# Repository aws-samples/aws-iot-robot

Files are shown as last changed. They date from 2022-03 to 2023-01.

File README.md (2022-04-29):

# AWS IoT Robot

The code and kit list in this repository enables the building of an AWS IoT and AWS Greengrass (v2) controlled Raspberry Pi robot.  This repository provides the code and assets for an AWS IoT workshop - please refer to that workshop (URL TBC) for detailed build instructions.

There are a number of physical components required to build the robot itself, and this has been done using readily available and low cost parts to hopefully give more people the opportunity to build their own IoT Robot.

## Introduction

You will need an AWS account in which to build this solution.  The solution demonstrates a number of different capabilities of AWS IoT and different ways of implementing those capabilities with the aim of bringing them together to help understand the different approaches and determine what is the best one for a given situation.

The core components of the solution are:
- A Web site/application - Using Angular, the web app displays robot movements, a WebRTC video stream from the PiBot camera and allows control of the camera direction
- Robot - A Raspberry Pi running AWS IoT Greengrass for managing the Lambda functions that control the PiBot actions
- Remote Control - A second Raspberry Pi (Pi Zero W) acts as a remote controller for the robot, using MQTT for communication over wireless.  The remote uses an accelerometer - you tilt the remote and the robot moves in that direction.

CloudFormation templates are provided to create the core AWS resources and also the AWS IoT specific resources.

## What will you build

A robot :-)

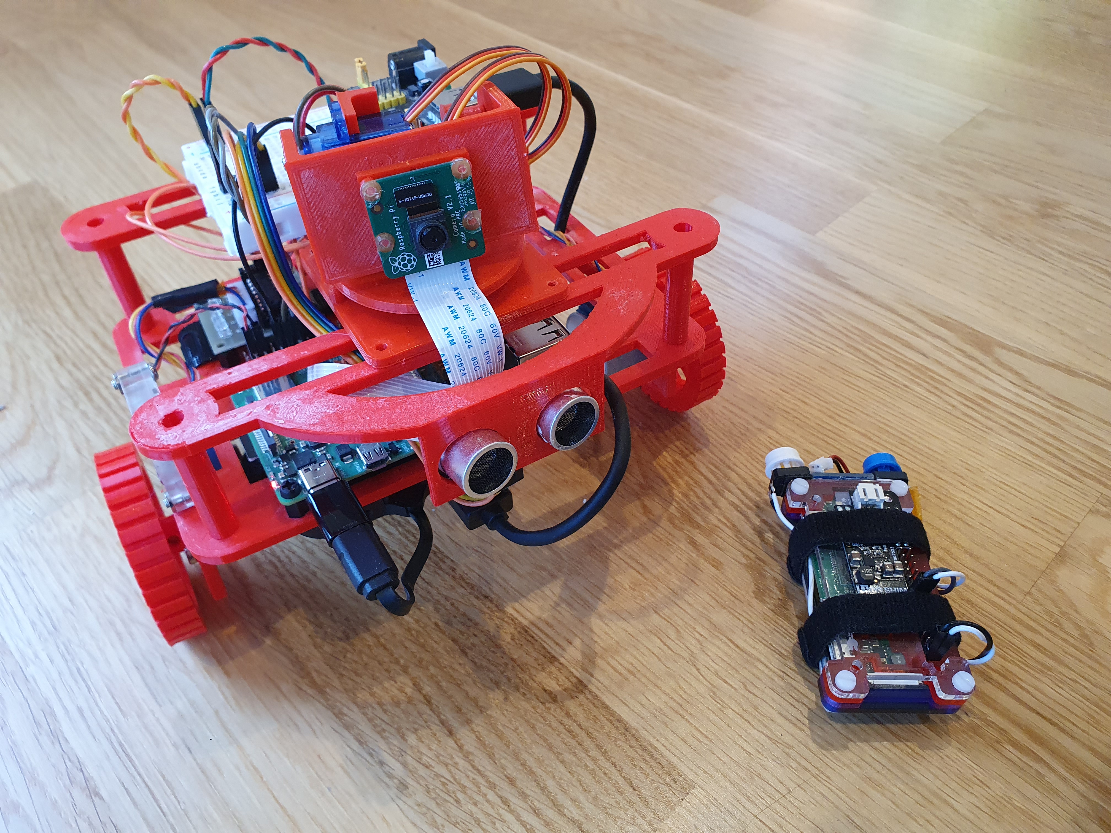
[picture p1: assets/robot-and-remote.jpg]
robot and remote


And a web application that can also control and track the robot and receives a video feed from the camera.

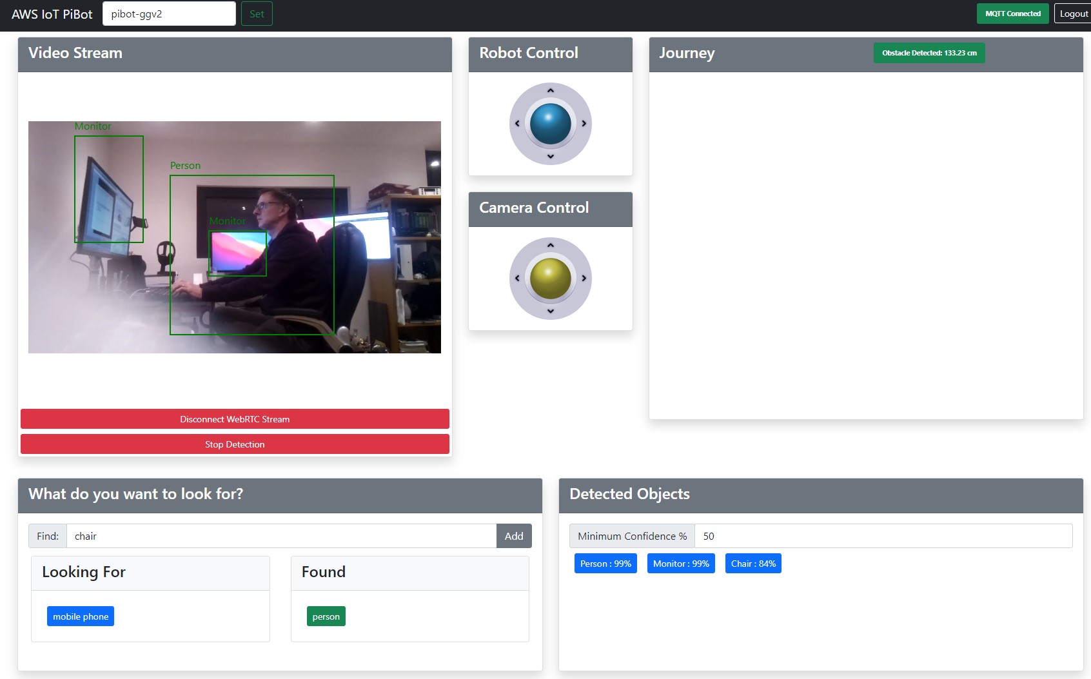
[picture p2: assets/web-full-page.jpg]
robot web application


## Architecture

The architecture diagram below shows the components of the service:

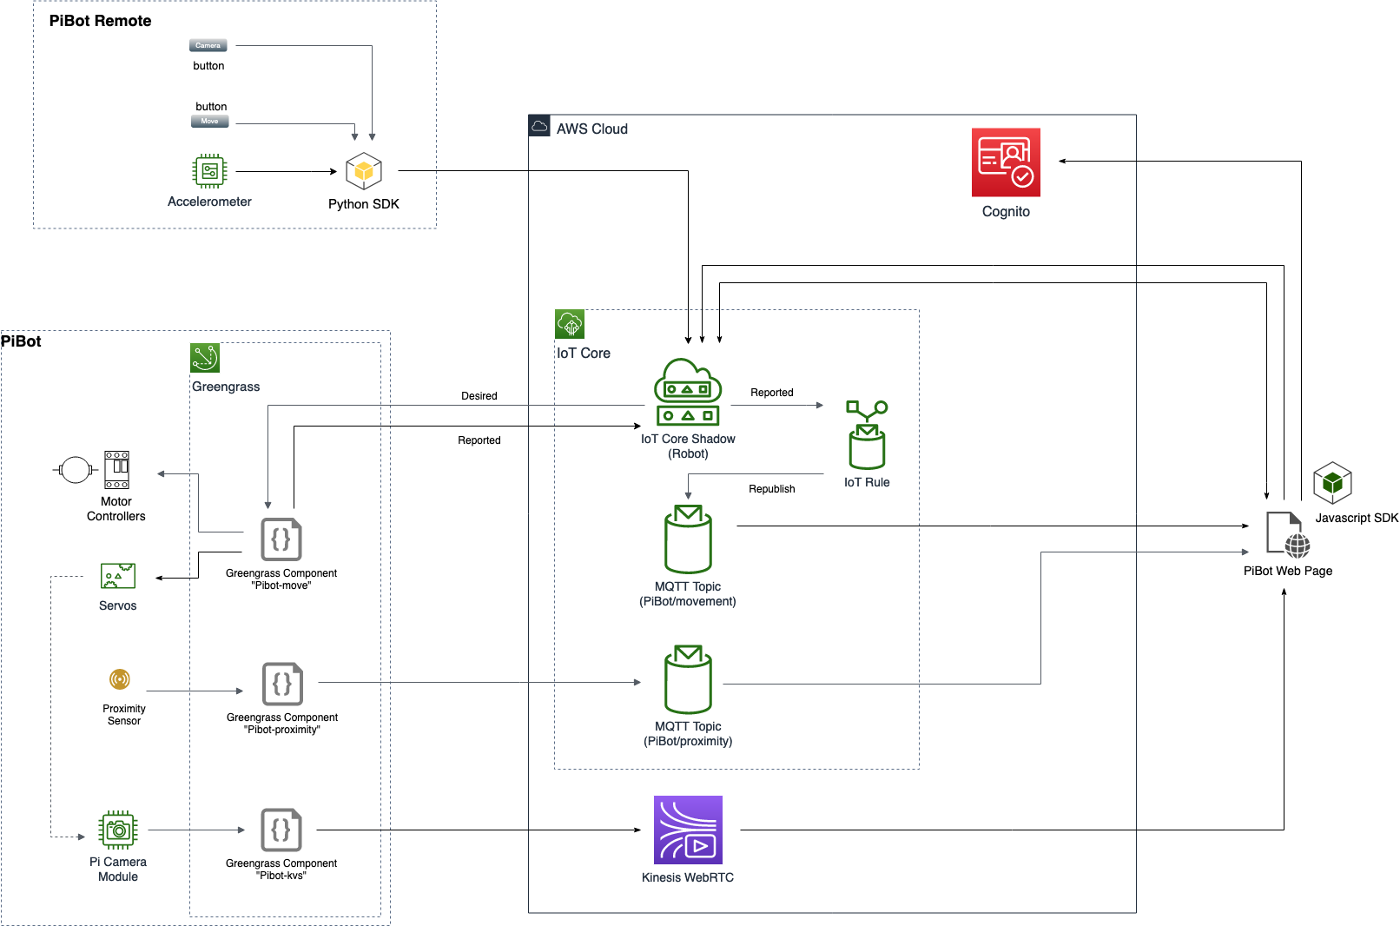
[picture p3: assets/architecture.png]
architecture


## Chassis Build

3D printer files are provided for the chassis of the robot, or you can use your own

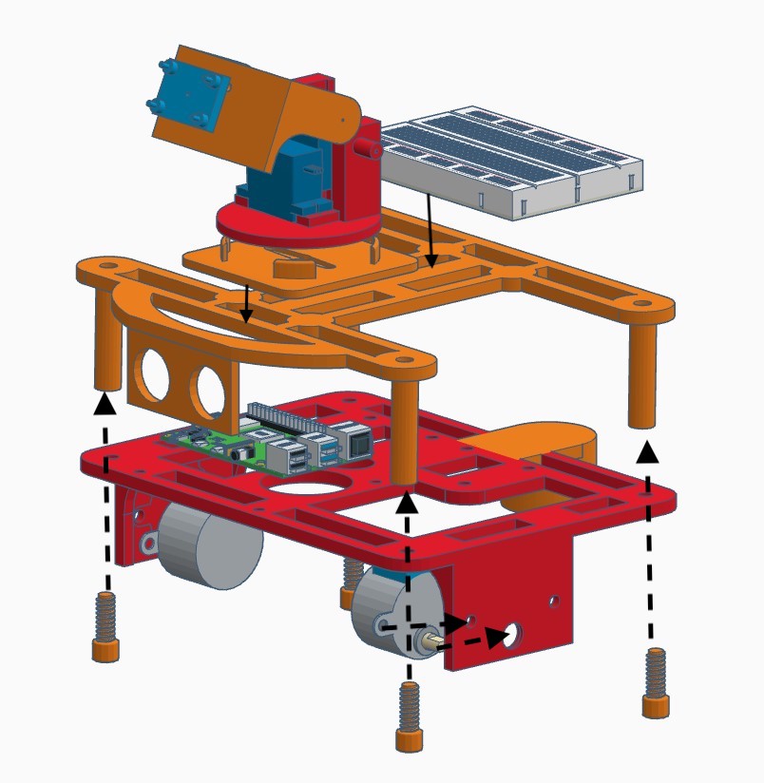
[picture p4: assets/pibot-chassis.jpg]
chassis


## How it works

### Communication Flow
The diagram below shows the communication flow between the PiRemote and PiBot, via IoT Core:

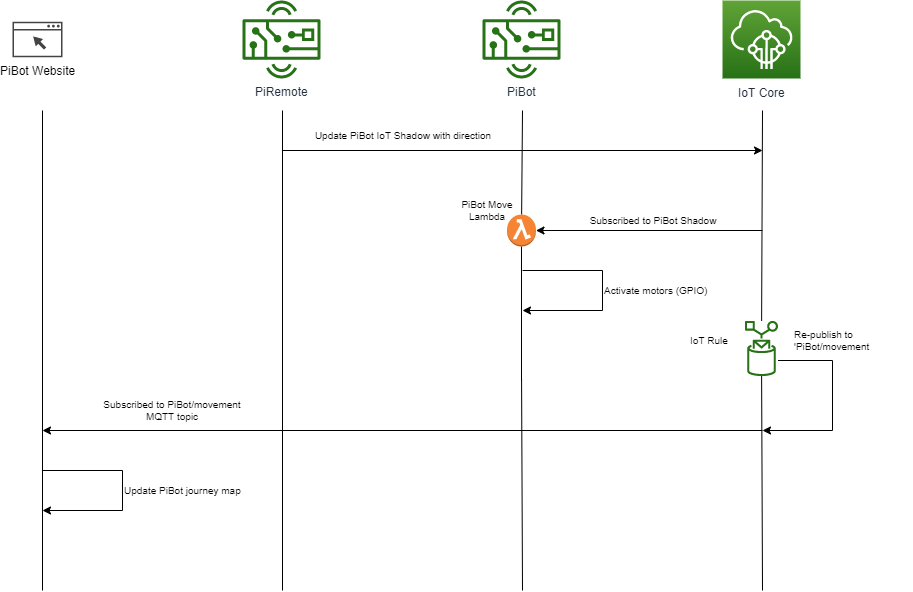
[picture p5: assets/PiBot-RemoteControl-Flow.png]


### Trusted User Provisioning App

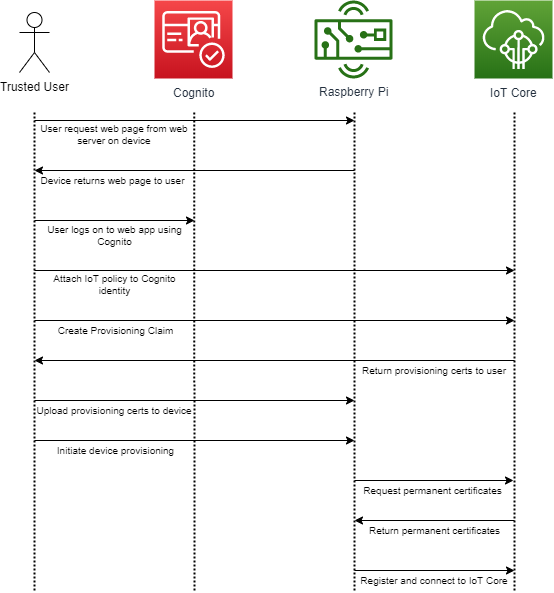
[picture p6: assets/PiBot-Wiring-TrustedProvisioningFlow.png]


## Parts List
The below list is not exhaustive and covers the key components required.  Additional components such as wheels, wiring, breadboard, batteries will be required to complete the build of a full robot
- Raspberry Pi 3 or 4
- Raspberry Pi Zero W (suggest using Lithium-Polymer battery and Li-Po shim)
- 2 x 28BYJ-48 Stepper Motor
- 2 x ULN2003 Motor Driver Board
- 1 x ADXL 345 Accelerometer
- 1 x HC-SR04 ultra-sonic proximity detector
- 2 x push buttons (normally open)
- 5v Battery pack suitable for driving Pi and motors

## Build

The overall build sequence is as follows:

- Setup a Cloud9 IDE
- Build the physical robot, chassis and electronics
- Create Cognito user pools using CloudFormation template
- Implement Greengrass pre-requisites (IAM roles, Fleet Provisioning Template)
- Build the Trusted User Provisioning application
- Provision the robot as an IoT Thing and Greengrass Core Device
- Install Kinesis WebRTC on the robot
- Create and deploy the Greengrass v2 Components
- Build the physical remote control (optional)
- Build the Robot web application
- Create an IoT rule for re-publishing

### Steps

Please refer to the AWS IoT Workshop (https://catalog.us-east-1.prod.workshops.aws/workshops/446304b7-b946-4c40-b78f-08bf0025d8f6) for detailed and step-by-step build instructions.

#### Wiring for PiBot GPIO Pins

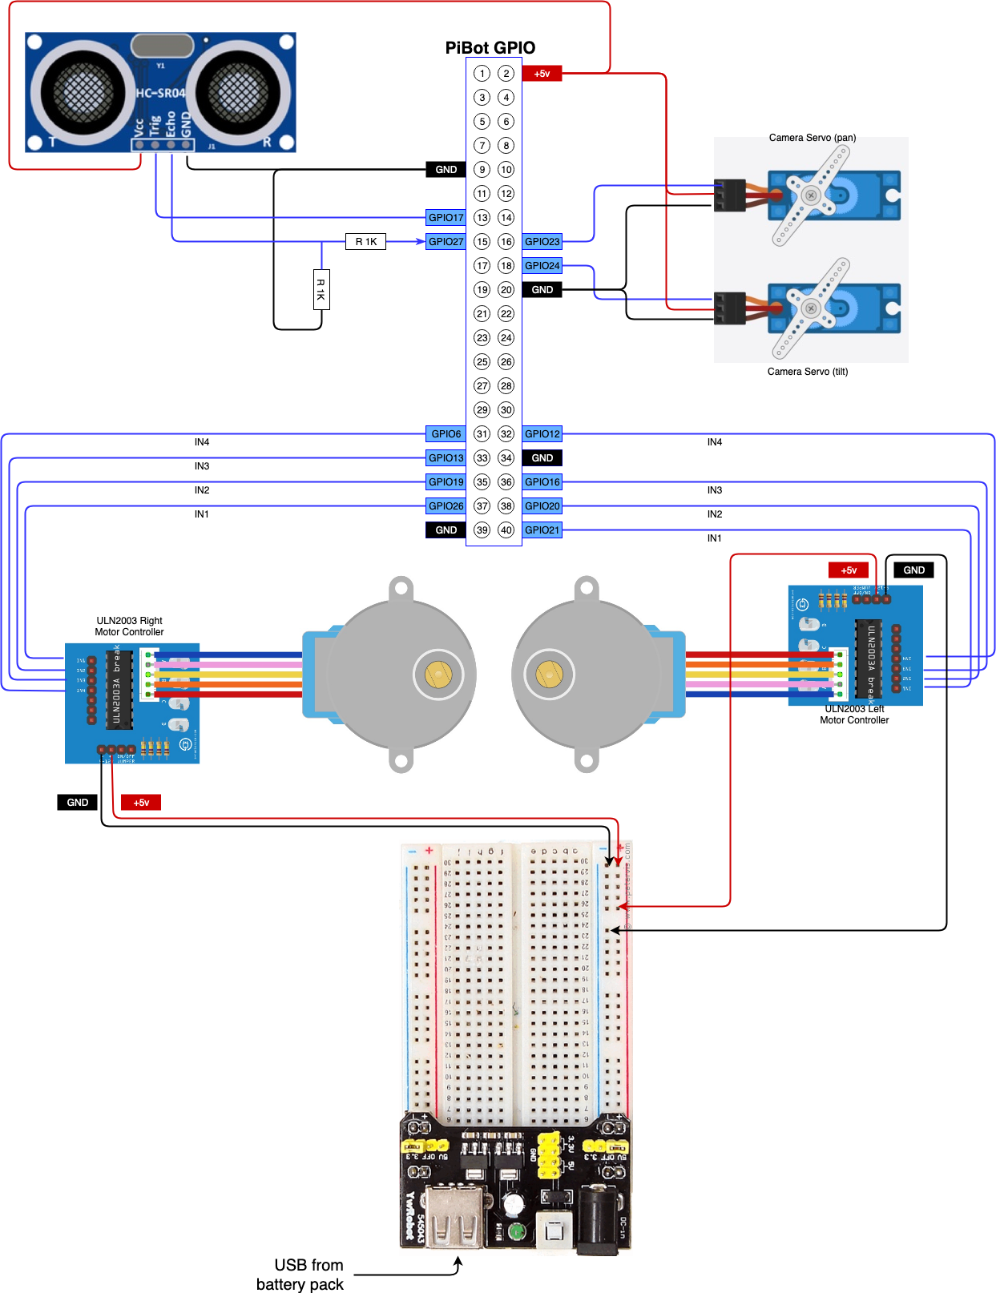
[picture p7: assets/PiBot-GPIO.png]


### Setting up PiRemote

The PiRemote uses the AWS SDK to connect to IoT Core, so does NOT need Greengrass installed.  The scripts on the Pi-Remote are Python 3 based - review the scripts for the Pi-zero-remote for the Python modules that you need to install to run the script.

There is no automated provisioning for the remote yet, so you will need to create the certificates in IoT Core for the Pi-Remote Thing and copy them to the device.  Adapting the PiBot Trusted User Provisioning web app should be pretty simple to provision the Pi-Remote in the same way.

#### Wiring for PiBot Remote GPIO Pins

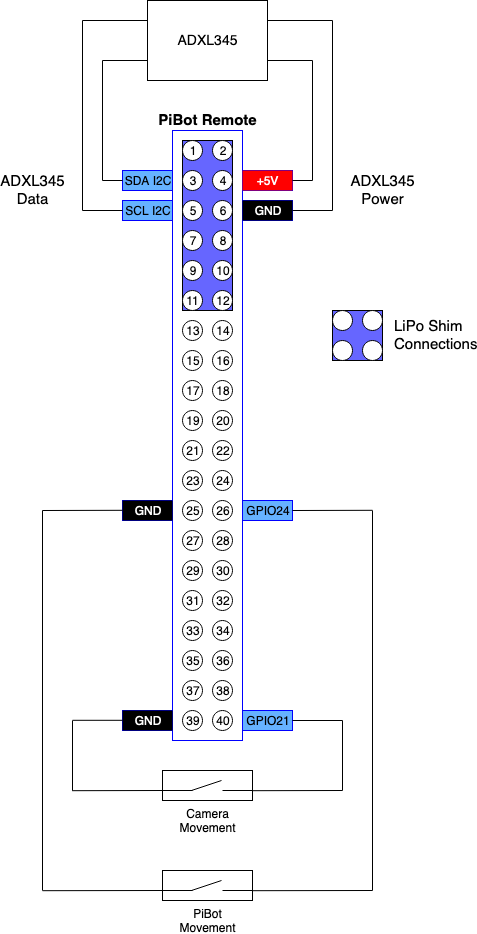
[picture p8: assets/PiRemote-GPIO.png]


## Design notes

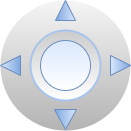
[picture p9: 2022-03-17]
PiBot-website/src/assets/joystick-base.png

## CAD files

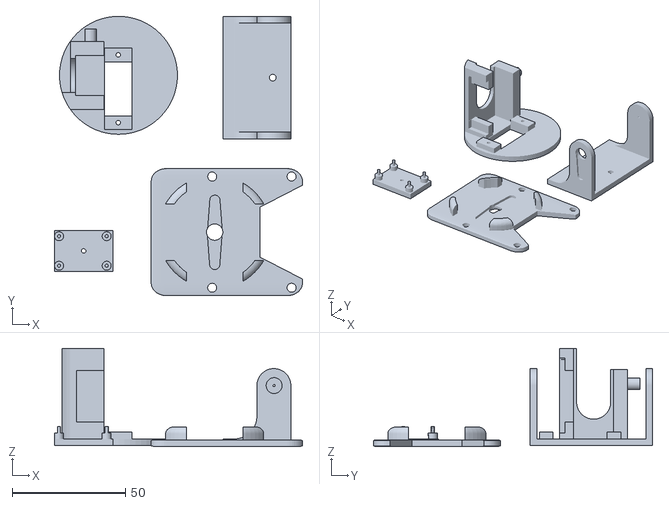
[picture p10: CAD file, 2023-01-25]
3D-Print-Files/camera-mount-single-layer-robot.stl
109.3 x 123.1 x 43.3

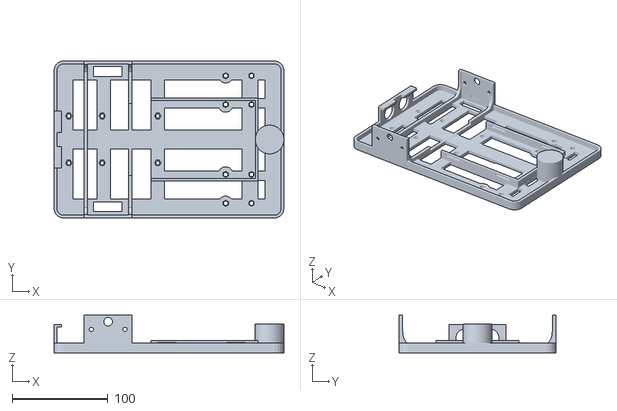
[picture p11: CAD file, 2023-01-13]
3D-Print-Files/Pibot Single Layer.stl
240.0 x 164.0 x 39.3

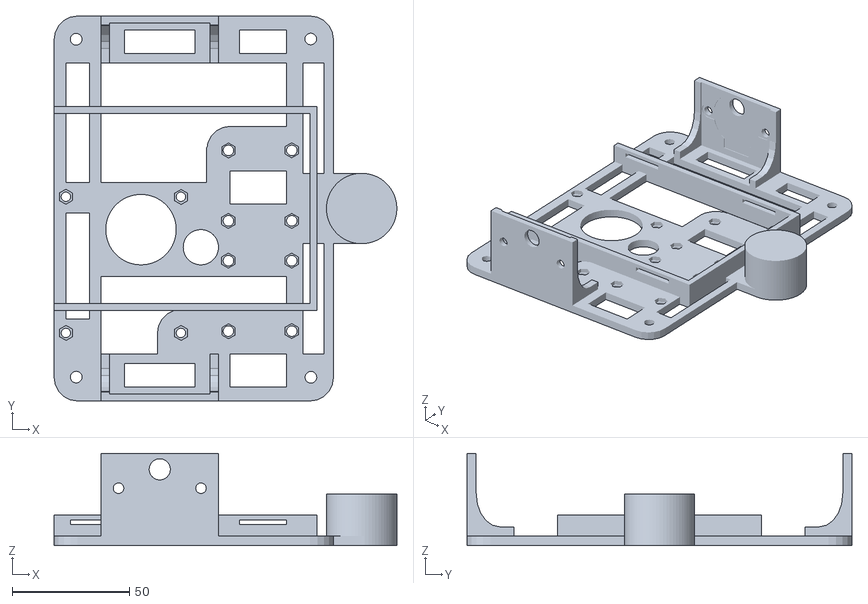
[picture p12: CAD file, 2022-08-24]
3D-Print-Files/Mini Pibot Bottom Layer.stl
146.0 x 164.0 x 39.3

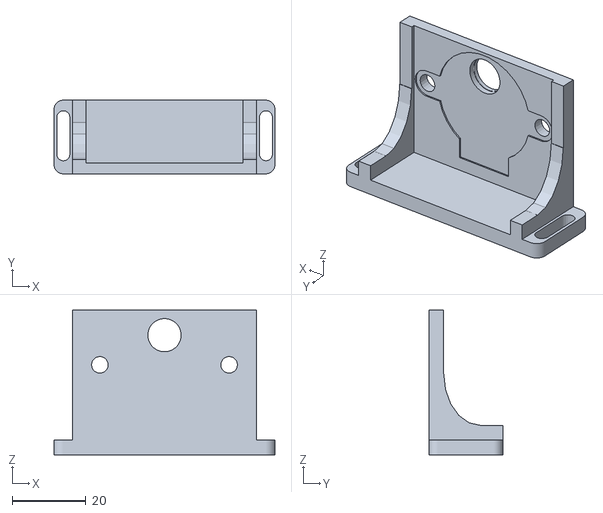
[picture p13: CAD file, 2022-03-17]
3D-Print-Files/Motor Brackets.stl
60.0 x 20.0 x 39.3

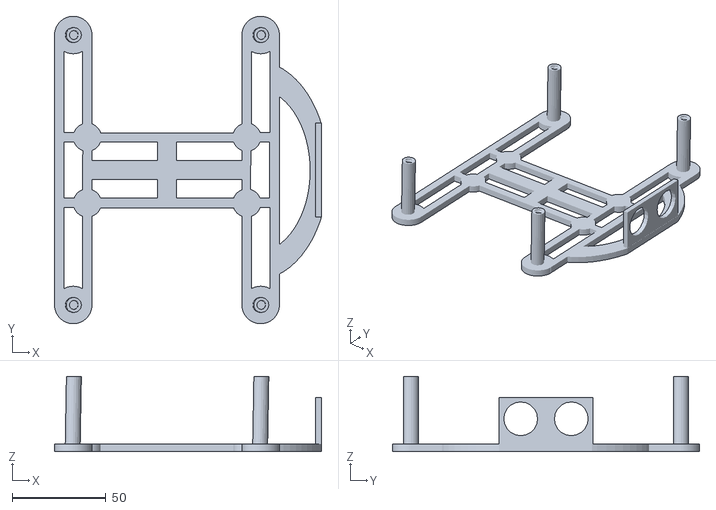
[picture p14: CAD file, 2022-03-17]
3D-Print-Files/Mini PiBot Top Layer.stl
142.4 x 164.0 x 40.1

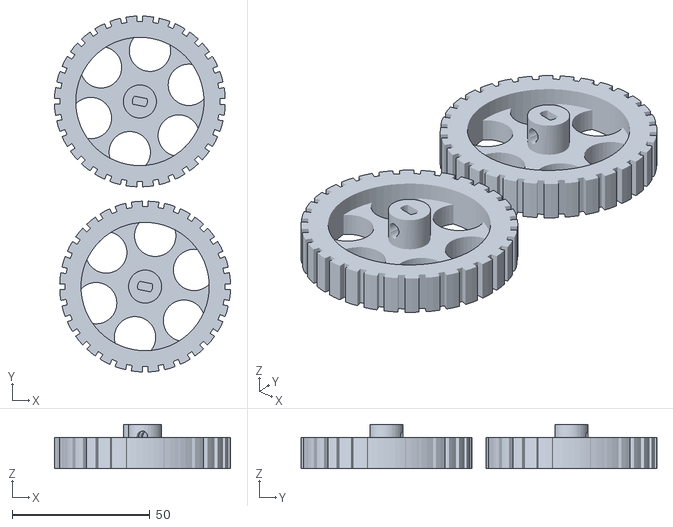
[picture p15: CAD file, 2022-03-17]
3D-Print-Files/Wheels.stl
63.8 x 129.0 x 16.0

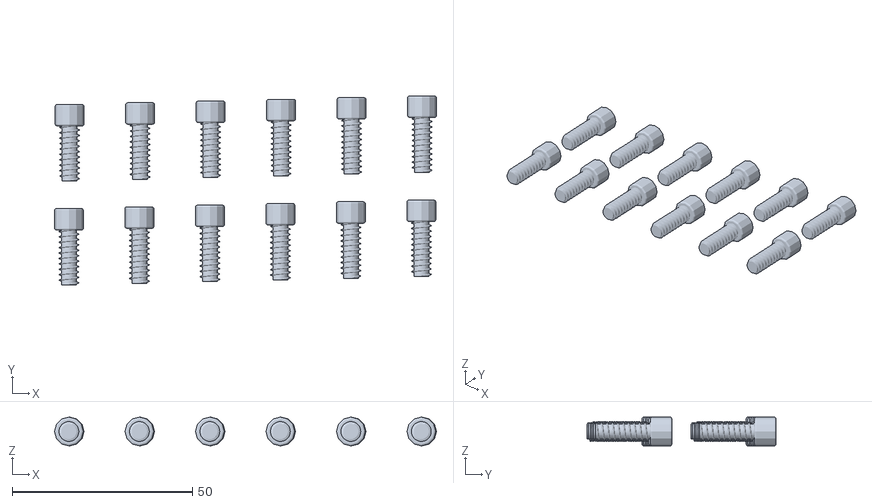
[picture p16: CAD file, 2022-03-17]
3D-Print-Files/Screws.stl
106.0 x 52.5 x 8.00

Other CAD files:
3D-Print-Files/Camera Mount.stl

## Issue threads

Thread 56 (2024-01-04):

Step 6 issues

noorjabermd, 2024-01-04:
Step 6.2.2
npm install error:
I had to reverse the changes in this pull-request (https://github.com/aws-samples/aws-iot-robot/pull/55/commits/0b7717e5619a81331b728307631ff1fa2f6265e2) in order to get npm install to complete. Happened on both 32-bit bullseye and 64-bit Bookworm running on a Raspi 4 4gb.

Step 6.3.3
Not really an issue as it automatically fixes this for you, but "sudo a2enmod cgi" should be "sudo a2enmod cgid".

Thanks,
Noor

gemmerton, 2024-01-10:
I'll re-test 6.2.2

Closed 2024-03-01.

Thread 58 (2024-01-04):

Step 9 issues

noorjabermd, 2024-01-04:
Step 9.3.1
typo
In the tutorial, the "exec_path" line of start-webrtc.py reads: "/homels/pi....". Removed ls -> /home/pi...
This file is imported into Cloud9 in the beginning of the tutorial and does not contain the typo. Consider adjusting the tutorial to only change line 8 with CRED_EP variable instead.

Step 9.4
Component module import error
I was not able to deploy the move and proximity components. In the /greengrass/v2/logs, I keep getting ModuleNotFoundError: No module named 'awsiot' for move and 'boto3' for proximity on line "import awsiot.greengrasscoreipc". I've made sure they (as well as awsiotsdk) are installed as user and that /home/pi/.local/bin was in PATH. I then installed the modules globally and added /home/pi/.local/bin as well as other potentially pertinent paths to PATH for all users and still couldn't deploy successfully. I recreated the component and added a "RequiresPrivilege": true, lifecycle hook, but that didn't deploy either. Input would be appreciated.

The KVS component deployed successfully and I was able to view the stream on AWS Kinesis dashboard on 32-bit Bullseye. In case you run this on 64-bit Bookworm, I had issues with gstreamer and followed the instructions [here](https://forums.raspberrypi.com/viewtopic.php?t=360578) to get streaming to show up.

Thanks,
Noor

gemmerton, 2024-01-05:
Hi Noor,
I've updated (but not yet published) the typo you've identified.

For the Python modules what I have found seems to be required is the following:

`sudo python3 -m pip install awsiotsdk boto3`

I suggest removing the Python libraries previously installed before running the above.

noorjabermd, 2024-01-05:
Thanks @gemmerton, that seemed to work.  I had to add awscli due to a boto3 version conflict.
Uninstall: sudo python3 -m pip uninstall awsiotsdk boto3 awscli
Reinstall: sudo python3 -m pip install awsiotsdk boto3 awscli
Deployed successfully afterwards.

Closed 2024-01-05.

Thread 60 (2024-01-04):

Step 13 Issue

noorjabermd, 2024-01-04:
Step 13.1
Site access error
When navigating to the cloudfront website, I kept getting access denied error. I double-checked the S3 bucket settings and troubleshooted [here](https://repost.aws/knowledge-center/s3-website-cloudfront-error-403) with no obvious reason as to why I was getting the error. Input would be appreciated.

Thanks,
Noor

gemmerton, 2024-01-05:
Hi Noor,
I think I've found the problem, and will update the workshop to cover this.  You'll need to edit the origin in your CloudFront distribution to add the region to the origin domain.  For example:

change:
my-robot-bucket.s3.amazonaws.com

to:
my-robot-bucket.s3.eu-west-1.amazonaws.com

obviously make sure the region you add is the region in which your S3 bucket exists.  Also make sure that when you change the origin domain, re-check that the Origin Access Identity is set correctly - I've seen this reset/clear when you change the domain so re-select if required.  Select "Legacy access identities" and the appropriate Origin access identity from the drop-down.

I will update this to use the more recent origin access control settings in a future release.

noorjabermd, 2024-01-05:
Thanks @gemmerton. That fixed the issue.
I'm now able to login and can select my device from the top left and I see MQTT is connected. Looking at the console, when I click "Connect to the WebRTC Stream" it seems to hang at "Generating ICE Candidates" as VIEWER with no output on the page. I can confirm video from the Pi can be viewed on the AWS KVS dashboard as well as the KVS WebRTC test page. Any ideas?

gemmerton, 2024-01-06:
Hi Noor,

First check is to confirm that the KVS signalling channel has the same name as the IoT Thing/Greengrass Core of the robot.  Have a look at the monitoring tab on the KVS console and you'll be able to see connection attempts by the master and the viewer.  As you're seeing video in the console you will see connections from the master (robot) and just need to see if viewer connections from the web app are also being seen.

I have seen on occassion what you are experiencing and in a lot of cases it has resolved itself by a reboot of the Pi (sorry, I always feel bad suggesting a reboot :-) )

noorjabermd, 2024-01-06:
Thanks @gemmerton.
Ha! No worries. I've rebooted without any change. Not sure why, but the Pibot Site's video stream will not load on Safari even though the WebRTC test page works fine (on Safari). I switched to chrome and I'm now able to see the video stream on the Pibot site. Thanks for all of your help and the tutorial.

gemmerton, 2024-01-10:
Hi Noor, are you okay to close this issue?

noorjabermd, 2024-01-11:
Happy to close. Thanks

Closed 2024-01-11.

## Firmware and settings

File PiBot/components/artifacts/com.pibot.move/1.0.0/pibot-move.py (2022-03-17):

#/*
# * Copyright Amazon.com, Inc. or its affiliates. All Rights Reserved.
# *
# * SPDX-License-Identifier: MIT-0
# * Permission is hereby granted, free of charge, to any person obtaining a copy of this
# * software and associated documentation files (the "Software"), to deal in the Software
# * without restriction, including without limitation the rights to use, copy, modify,
# * merge, publish, distribute, sublicense, and/or sell copies of the Software, and to
# * permit persons to whom the Software is furnished to do so.
# *
# * THE SOFTWARE IS PROVIDED "AS IS", WITHOUT WARRANTY OF ANY KIND, EXPRESS OR IMPLIED,
# * INCLUDING BUT NOT LIMITED TO THE WARRANTIES OF MERCHANTABILITY, FITNESS FOR A
# * PARTICULAR PURPOSE AND NONINFRINGEMENT. IN NO EVENT SHALL THE AUTHORS OR COPYRIGHT
# * HOLDERS BE LIABLE FOR ANY CLAIM, DAMAGES OR OTHER LIABILITY, WHETHER IN AN ACTION
# * OF CONTRACT, TORT OR OTHERWISE, ARISING FROM, OUT OF OR IN CONNECTION WITH THE
# * SOFTWARE OR THE USE OR OTHER DEALINGS IN THE SOFTWARE.
# */

import time
import sys
import threading
import traceback
import json
import RPi.GPIO as gpio

import awsiot.greengrasscoreipc
import awsiot.greengrasscoreipc.client as client
from awsiot.greengrasscoreipc.model import (
    SubscribeToIoTCoreRequest,
    PublishToIoTCoreRequest,
    QOS,
    IoTCoreMessage
)
#from awsiot.greengrasscoreipc.model import GetThingShadowRequest
#from awsiot.greengrasscoreipc.model import UpdateThingShadowRequest

ipc_client = awsiot.greengrasscoreipc.connect()
camera_pin_x = int(sys.argv[1])
camera_pin_y = int(sys.argv[2])
lcoil_pins = list(map(int,sys.argv[3].split(",")))
rcoil_pins = list(map(int,sys.argv[4].split(",")))
TIMEOUT = 10
client_id = sys.argv[5]
thing_name = sys.argv[5]

subscribe_topic = "$aws/things/"+thing_name+"/shadow/update/accepted"
publish_topic = "$aws/things/"+thing_name+"/shadow/update"
sub_qos = QOS.AT_MOST_ONCE
pub_qos = QOS.AT_LEAST_ONCE
shadow_value = { "move_x": "S", "move_y": "S", "cam_x": "S", "cam_y": "S" }
camera_angle_x = 90
camera_angle_y = 90

gpio.setmode(gpio.BCM)
gpio.setwarnings(False)

step_count = 8
seq_f = list(range(0,step_count))
seq_f = [[1,0,0,0],[1,1,0,0],[0,1,0,0],[0,1,1,0],[0,0,1,0],[0,0,1,1],[0,0,0,1],[1,0,0,1]]

seq_r = list(range(0,step_count))
seq_r = [[1,0,0,1],[0,0,0,1],[0,0,1,1],[0,0,1,0],[0,1,1,0],[0,1,0,0],[1,1,0,0],[1,0,0,0]]

for lpin,rpin in zip(lcoil_pins,rcoil_pins):
    gpio.setup(lpin,gpio.OUT)
    gpio.setup(rpin,gpio.OUT)

gpio.setup(camera_pin_x,gpio.OUT)
gpio.setup(camera_pin_y,gpio.OUT)

class MotorThread(threading.Thread):
    def __init__(self,motor_name,pins,delay=0.01,direction="S"):
        threading.Thread.__init__(self)

        self.thread_id = motor_name
        self.direction = direction
        self.delay = delay
        self.pins = pins

        self.terminate_event = threading.Event()
        self.start_event = threading.Event()
        self.reset_event = threading.Event()

    def run(self):
        while not self.terminate_event.is_set():
            while self.start_event.is_set():
                if self.direction == "f":
                    self.do_steps(seq_f)
                elif self.direction == "b":
                    self.do_steps(seq_r)

    def set_direction(self,direction):
        self.direction = direction

    def set_delay(self,delay):
        self.delay = delay

    def start_motor(self):
        self.start_event.set()

    def stop_motor(self):
        self.start_event.clear()

    def set_steps(self,num_steps):
        self.num_steps = num_steps

    def do_steps(self,arr):
        for steps in range(self.num_steps):
            for step in range(step_count):
                pin_idx = 0
                for pin in self.pins:
                    gpio.output(pin,arr[step][pin_idx])
                    pin_idx += 1
                time.sleep(self.delay)

    def restart_motor(self):
        # reset only if motor is running. otherwise start motor afresh
        if self.start_event.is_set():
            self.reset_event.set()
        else:
            self.start_event.set()

    def terminate(self):
        self.terminate_event.set()

class CameraThread(threading.Thread):
    def __init__(self,servo_name,servo_pin,angle=90,dir="f"):
        threading.Thread.__init__(self)

        print("Init servo:",servo_name,servo_pin)
        self.servo = gpio.PWM(servo_pin, 100)
        self.name = servo_name
        self.angle = angle
        self.dir = dir
        self.angle = 90
        self.set_angle(self.angle)

        self.start_event = threading.Event()
        self.terminate_event = threading.Event()

    def run(self):
        print("run")

    def start_servo(self):
        self.servo.start(5)

    def set_angle(self,angle):
        print("Setting angle:",self.name,angle)
        self.angle = angle
        duty = float(angle) / 10.0 + 2.5
        self.servo.ChangeDutyCycle(duty)

    def get_angle(self):
        return int(self.angle)

    def stop_servo(self):
        print("Stopping servo",self.name)
        self.servo.ChangeDutyCycle(0)

    def terminate(self):
        self.terminate_event.set()

class StreamHandler(client.SubscribeToIoTCoreStreamHandler):
    def __init__(self):
        super().__init__()

    def on_stream_event(self, event: IoTCoreMessage) -> None:
        try:
            message_string = str(event.message.payload, "utf-8")
            # Load message and check values
            jsonmsg = json.loads(message_string)

            if jsonmsg['state']['desired']['direction']:
                print("Move motor or camera: ",jsonmsg)
                if "move_x" in jsonmsg['state']['desired']['direction']:
                    set_motor_direction(jsonmsg['state']['desired']['direction'])
                if "cam_x" in jsonmsg['state']['desired']['direction']:
                    set_camera_angle(jsonmsg['state']['desired']['direction'])
                #pub_thread.publish(jsonmsg)
        except:
            traceback.print_exc()

    def on_stream_error(self, error: Exception) -> bool:
        # Handle error.
        return True  # Return True to close stream, False to keep stream open.

    def on_stream_closed(self) -> None:
        # Handle close.
        pass

class update_thing_shadow_request(threading.Thread):
    def __init__(self,name="pub"):
        threading.Thread.__init__(self)
        self.name = name

    def run(self):
        print("run")

    def set_topic(self,topic):
        self.topic = topic

    def publish(self,payload):
        try:
            payload['state']['reported'] = payload['state']['desired']
            pub_req = PublishToIoTCoreRequest()
            pub_req.topic_name = self.topic
            pub_req.payload = json.dumps(payload).encode('utf-8')
            pub_req.qos = pub_qos
            send_msg = ipc_client.new_publish_to_iot_core()
            send_msg.activate(pub_req)
            msg_resp = send_msg.get_response()
            #msg_resp.result(TIMEOUT)
        except Exception as e:
            print("Error update shadow", type(e), e)
            # except ConflictError | UnauthorizedError | ServiceError

def set_motor_direction(direction):
    # set the direction for the motors based on shadow values
    # this function only called if the shadow value has changed
    motor_l_delay = 0.0008
    motor_r_delay = 0.0008

    if direction['move_x'] == "F":
        #print("Forward")
        motorL.set_direction("f")
        motorR.set_direction("b")
        if direction['move_y'] == "L":
            #print(" and to the left")
            motor_l_delay *= 2
        elif direction['move_y'] == "R":
            #print(" and to the right")
            motor_r_delay *= 2 
    elif direction['move_x'] == "B":
        #print("Backwards")
        motorL.set_direction("b")
        motorR.set_direction("f")
        if direction['move_y'] == "L":
            #print(" and to the left")
            motor_r_delay *= 2
        elif direction['move_y'] == "R":
            #print(" and to the right")
            motor_l_delay *= 2
    elif direction['move_x'] == "S":
        # pure left or right, so both motors in same dir at same speed
        if direction['move_y'] == "L":
            #print("Only Left")
            motorL.set_direction("b")
            motorR.set_direction("b")
        elif direction['move_y'] == "R":
            #print("Only Right")
            motorL.set_direction("f")
            motorR.set_direction("f")

    if direction['move_x'] != "S" or direction['move_y'] != "S":
        motorL.set_delay(motor_l_delay)
        motorR.set_delay(motor_r_delay)
        motorL.set_steps(100)
        motorR.set_steps(100)
        motorL.start_motor()
        motorR.start_motor()
    else:
        motorL.stop_motor()
        motorR.stop_motor()

def set_camera_angle(direction):
    #print("Set camera angle:",direction['cam_x'],direction['cam_y'])

    if (servoX.get_angle() != int(direction['cam_x'])):
        servoX.start_servo()
        servoX.set_angle(int(direction['cam_x']))
        time.sleep(0.5)
        servoX.stop_servo()

    if (servoY.get_angle() != int(direction['cam_y'])):
        servoY.start_servo()
        servoY.set_angle(int(direction['cam_y']))
        time.sleep(0.5)
        servoY.stop_servo()

print("Launching thread to manage motors...")
motorL = MotorThread("LeftMotor",lcoil_pins)
motorL.start()
motorR = MotorThread("RightMotor",rcoil_pins)
motorR.start()
print("motor init complete")

print("Launching Camera servo threads")
servoX = CameraThread("axis_x",camera_pin_x)
servoY = CameraThread("axis_y",camera_pin_y)

#subscribe to shadow update topic
print("Subscribing to MQTT topic for shadow")
request = SubscribeToIoTCoreRequest()
request.topic_name = subscribe_topic 
request.qos = sub_qos
handler = StreamHandler()
operation = ipc_client.new_subscribe_to_iot_core(handler) 
future = operation.activate(request)
future.result(TIMEOUT)
print("Finished subscription")

pub_thread = update_thing_shadow_request("pub_shadow")
pub_thread.set_topic(publish_topic)

# Keep main thread running
while True:
    time.sleep(10)

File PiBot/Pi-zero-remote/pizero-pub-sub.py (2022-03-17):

# Copyright Amazon.com, Inc. or its affiliates. All Rights Reserved.
# SPDX-License-Identifier: Apache-2.0.
# Modifications Copyright 2022 Amazon.com, Inc. or its affiliates. Licensed under the MIT-0 License.

import argparse
from awscrt import io, mqtt, auth, http
from awsiot import mqtt_connection_builder
import sys
import threading
import time
from uuid import uuid4
import json
import time

## AWS IoT Robot modifications
import board
import busio
import adafruit_adxl34x
import RPi.GPIO as GPIO

# for the accelerometer module
i2c = busio.I2C(board.SCL, board.SDA)
accelerometer = adafruit_adxl34x.ADXL345(i2c)

# for the push button
move_button_gpio = 7
camera_button_gpio = 21
GPIO.setwarnings(False)
GPIO.setmode(GPIO.BCM)
GPIO.setup(move_button_gpio, GPIO.IN, pull_up_down=GPIO.PUD_UP) # Move button - initialises with down/off
GPIO.setup(camera_button_gpio, GPIO.IN, pull_up_down=GPIO.PUD_UP) # Camera button

# For capturing current vals so only publish message on change
current_vals = {}
received_count = 0
received_all_event = threading.Event()
payload = { "move_x": "S", "move_y": "S", "cam_x": "S", "cam_y": "S" }
## END AWS IoT Robot modifications

parser = argparse.ArgumentParser(description="Send and receive messages through and MQTT connection.")
parser.add_argument('--endpoint', required=True, help="Your AWS IoT custom endpoint, not including a port. " +
                                                      "Ex: \"abcd123456wxyz-ats.iot.us-east-1.amazonaws.com\"")
parser.add_argument('--port', type=int, help="Specify port. AWS IoT supports 443 and 8883.")
parser.add_argument('--cert', help="File path to your client certificate, in PEM format.")
parser.add_argument('--key', help="File path to your private key, in PEM format.")
parser.add_argument('--root-ca', help="File path to root certificate authority, in PEM format. " +
                                      "Necessary if MQTT server uses a certificate that's not already in " +
                                      "your trust store.")
parser.add_argument('--client-id', default="pi-remote", help="Client ID for MQTT connection.")
parser.add_argument('--topic', default="$aws/things/pb_pibot/shadow/update", help="Topic to subscribe to, and publish messages to.")
parser.add_argument('--verbosity', choices=[x.name for x in io.LogLevel], default=io.LogLevel.NoLogs.name,
    help='Logging level')

# Using globals to simplify sample code
args = parser.parse_args()

io.init_logging(getattr(io.LogLevel, args.verbosity), 'stderr')

# Callback when connection is accidentally lost.
def on_connection_interrupted(connection, error, **kwargs):
    print("Connection interrupted. error: {}".format(error))

# Callback when an interrupted connection is re-established.
def on_connection_resumed(connection, return_code, session_present, **kwargs):
    print("Connection resumed. return_code: {} session_present: {}".format(return_code, session_present))

    if return_code == mqtt.ConnectReturnCode.ACCEPTED and not session_present:
        print("Session did not persist. Resubscribing to existing topics...")
        resubscribe_future, _ = connection.resubscribe_existing_topics()

        # Cannot synchronously wait for resubscribe result because we're on the connection's event-loop thread,
        # evaluate result with a callback instead.
        resubscribe_future.add_done_callback(on_resubscribe_complete)

def on_resubscribe_complete(resubscribe_future):
        resubscribe_results = resubscribe_future.result()
        print("Resubscribe results: {}".format(resubscribe_results))

        for topic, qos in resubscribe_results['topics']:
            if qos is None:
                sys.exit("Server rejected resubscribe to topic: {}".format(topic))

# Callback when the subscribed topic receives a message
def on_message_received(topic, payload, dup, qos, retain, **kwargs):
    print("Received message from topic '{}': {}".format(topic, payload))

## AWS IoT Robot modifications
# Get accelerometer and button values
def get_accelerometer():
    while True:
        #print("%f %f %f"%accelerometer.acceleration)
        time.sleep(0.25)
        acc = accelerometer.acceleration
        changed = False

        # X Axis - set forward or backward
        if int(acc[0]) >= 2:
            x = "F"
        elif int(acc[0]) <= -2:
            x = "B"
        else:
            x = "S"

        # Y Axis - set left or right
        if int(acc[1]) >= 2:
            y = "L"
        elif int(acc[1]) <= -2:
            y = "R"
        else:
            y = "S"

        # if button not pressed then stop if not already done sone
        if GPIO.input(move_button_gpio) == GPIO.HIGH:
            if payload["move_x"] != "S" or payload["move_y"] != "S":
                # stop movement as button not pressed
                changed = True
                payload["move_x"] = "S"
                payload["move_y"] = "S"
        else:
            if x != payload["move_x"] or y != payload["move_y"]:
                # Move button pressed so update movement
                changed = True
                payload["move_x"] = x
                payload["move_y"] = y


        if GPIO.input(camera_button_gpio) == GPIO.HIGH:
            if payload["cam_x"] != "S" or payload["cam_y"] != "S":
                # stop movement as button not pressed
                changed = True
                payload["cam_x"] = "S"
                payload["cam_y"] = "S"
        else:
            if x != payload["cam_x"] or y != payload["cam_y"]:
                # Move button pressed so update movement
                changed = True
                payload["cam_x"] = x
                payload["cam_y"] = y

        # Publish to PiBot shadow topic, but only if changed
        if changed:
            publish_message(payload)

def publish_message(message):
    full_msg = { "state": { "desired": { "direction": message } } }
    message_json = json.dumps(full_msg)
    #print("Publishing: ",full_msg)
    mqtt_connection.publish(
        topic=args.topic,
        payload=message_json,
        qos=mqtt.QoS.AT_LEAST_ONCE)
## END AWS IoT Robot modifications
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

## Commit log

2022-03-17 Bump aws-iot-device-sdk-v2 from 1.5.2 to 1.6.0 in /PiBot-website
    Bumps [aws-iot-device-sdk-v2](https://github.com/aws/aws-iot-device-sdk-js-v2) from 1.5.2 to 1.6.0.
    - [Release notes](https://github.com/aws/aws-iot-device-sdk-js-v2/releases)
    - [Commits](https://github.com/aws/aws-iot-device-sdk-js-v2/compare/v1.5.2...v1.6.0)
    ---
    updated-dependencies:
    - dependency-name: aws-iot-device-sdk-v2
    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
2022-08-24 updated 3d print files
    [Camera Mount.stl, Mini Pibot Bottom Layer.stl]
2022-11-22 Bump engine.io and socket.io in /PiBot-provisioning-app
    Bumps [engine.io](https://github.com/socketio/engine.io) and [socket.io](https://github.com/socketio/socket.io). These dependencies needed to be updated together.
    Updates `engine.io` from 6.1.3 to 6.2.1
    - [Release notes](https://github.com/socketio/engine.io/releases)
    - [Changelog](https://github.com/socketio/engine.io/blob/main/CHANGELOG.md)
    - [Commits](https://github.com/socketio/engine.io/compare/6.1.3...6.2.1)
    Updates `socket.io` from 4.4.1 to 4.5.3
    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
2022-11-22 Bump engine.io and socket.io in /PiBot-website
    - [Release notes](https://github.com/socketio/socket.io/releases)
    - [Changelog](https://github.com/socketio/socket.io/blob/main/CHANGELOG.md)
    - [Commits](https://github.com/socketio/socket.io/c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
2023-01-25 3d print file additions
    [camera-mount-single-layer-robot.stl]
2023-05-24 Bump socket.io-parser from 4.2.2 to 4.2.3 in /PiBot-provisioning-app
    Bumps [socket.io-parser](https://github.com/socketio/socket.io-parser) from 4.2.2 to 4.2.3.
    - [Release notes](https://github.com/socketio/socket.io-parser/releases)
    - [Changelog](https://github.com/socketio/socket.io-parser/blob/main/CHANGELOG.md)
    - [Commits](https://github.com/socketio/socket.io-parser/compare/4.2.2...4.2.3)
    - dependency-name: socket.io-parser
    dependency-type: indirect
    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
2023-05-24 Bump socket.io-parser from 4.2.2 to 4.2.3 in /PiBot-website
    ...
    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
2024-06-20 Bump ws, engine.io and socket.io-adapter in /PiBot-website
    Bumps [ws](https://github.com/websockets/ws), [engine.io](https://github.com/socketio/engine.io) and [socket.io-adapter](https://github.com/socketio/socket.io-adapter). These dependencies needed to b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
    Updates `ws` from 8.11.0 to 8.17.1
    - [Release notes](https://github.com/websockets/ws/releases)
    - [Commits](https://github.com/websockets/ws/compare/8.11.0...8.17.1)
    Updates `engine.io` from 6.5.4 to 6.5.5
    - [Commits](https://github.com/socketio/engine.io/compare/6.5.4...6.5.5)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
2024-06-20 Bump ws and socket.io in /PiBot-provisioning-app
    Bumps [ws](https://github.com/websockets/ws) and [socket.io](https://github.com/socketio/socket.io). These dependencies needed to be updated together.
    Updates `socket.io` from 4.6.2 to 4.7.5
    - [Commits](https://github.com/socketio/socket.io/compare/4.6.2...4.7.5)
    - dependency-name: ws
    dependency-type: indirect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
2024-06-20 Bump ws and socket.io-adapter in /PiBot-provisioning-app
    Bumps [ws](https://github.com/websockets/ws) and [socket.io-adapter](https://github.com/socketio/socket.io-adapter). These dependencies needed to be updated together.
    Updates `socket.io-adapter` from 2.5.2 to 2.5.5
    - [Release notes](https://github.com/socketio/socket.io-adapter/releases)
    - [Changelog](https://github.com/socketio/socket.io-adapter/blob/main/CHANGELOG.md)
    - [Commits](https://github.com/socketio/socket.io-adapter/compare/2.5.2...2.5.5)
    updated-dependen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
2024-10-10 Bump cookie, socket.io and express in /PiBot-website
    Bumps [cookie](https://github.com/jshttp/cookie), [socket.io](https://github.com/socketio/socket.io) and [express](https://github.com/expressjs/express). These dependencies needed to be updated toget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
    Updates `cookie` from 0.4.2 to 0.7.2
    - [Release notes](https://github.com/jshttp/cookie/releases)
    - [Commits](https://github.com/jshttp/cookie/compare/v0.4.2...v0.7.2)
    Updates `socket.io` from 4.7.5 to 4.8.0
    - [Commits](https://github.com/socketio/socket.io/compare/socket.io@4.7.5...socket.io@4.8.0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
2024-10-10 Bump cookie, socket.io and express in /PiBot-provisioning-app
    - [Commits](https://github.com/socketio/socket.io/compare/socket.io@4.7.5...socket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
2026-07-16 Bump websocket-driver from 0.7.4 to 0.7.5 in /PiBot-website
    Bumps [websocket-driver](https://github.com/faye/websocket-driver-node) from 0.7.4 to 0.7.5.
    - [Changelog](https://github.com/faye/websocket-driver-node/blob/main/CHANGELOG.md)
    - [Commits](https://github.com/faye/websocket-driver-node/compare/0.7.4...0.7.5)
    - dependency-name: websocket-driver
    dependency-version: 0.7.5
    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
2026-07-17 Bump websocket-driver from 0.7.4 to 0.7.5 in /PiBot-provisioning-app
    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
